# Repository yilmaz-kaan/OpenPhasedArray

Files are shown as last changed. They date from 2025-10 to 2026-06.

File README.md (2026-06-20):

# beamers
Rice University 2025-2026 ECE Senior Capstone Project Repository
Team BEAMFORM

The OpenPhasedArray is an open-source, modular 4-element transceiver phased-array
board adaptable across software-defined radio platforms and optimized for S-band
frequencies. It is ideal for hobby or research-grade beamforming experiments or sensing
and communications prototyping. It is a modular design that is easily stackable both
vertically and horizontally using the provided 3D-printable board mount. It is (optionally) interfaced with by the FT232H USB-to-serial
converter for easy, Python-based control. 

**Specification and Info**
- 2.4 – 3.7 GHz operating frequency
- Small form factor, 4.128” x 3.534”
- 21 dB peak gain per channel in TX
- 14 dB peak gain per channel in RX
- 5.625° nominal phase shifter resolution with 64 states
- 0.254 dB attenuator resolution with 128 states
- 500 ns typical TX/RX switching time
- 6V DC Power thru barrel jack-- 16V maximum
- <1mA quiescent current, 700mA maximum @ 6V input

**Repo Contents**
- Hardware
    - OpenPhasedArray schematic, design, and gerber files
    - Evaluation boards for most RF components used on the OpenPhasedArray
    - An 8-element microstrip patch antenna array that can be paired with the OpenPhasedArray
    - The original 'TXBoard' Prototype schematic, design, and gerber files
    - The secondary 'TXBoard2' Prototype schematic, design, and gerber files
    - 'STM32EVAL,' an experiment for future revisions that allow much larger scale integration
- Software
    - Control code for various versions of the board, except for Rev. 2 due to layout errors.
    - Leftover code and scripts from testing and demonstrating board performance in an Anechoic chamber

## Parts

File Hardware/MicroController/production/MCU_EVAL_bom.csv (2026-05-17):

Designator | Footprint | Quantity | Value | LCSC Part #
C1, C14, C20 | 0603 | 3 | 10uF
C15, C17, C18, C21, C25, C26, C27, C28, C30 | 0402 | 9 | 100nF
C16, C3 | 0402 | 2 | 10pF
C22, C23 | 0603 | 2 | 2u2F
C24 | 0603 | 1 | 4u7F
C29 | 0402 | 1 | 1uF
C4, C9 | 0402 | 2 | 30pF
D1 | LTST-C190KGKT | 1 | BLINK
D2 | SOD3715X145N | 1 | 1N5819HW-7-F
D3 | LTST-C190KGKT | 1 | PWRLED
J1 | HRO_TYPE-C-31-M-12 | 1 | TYPE-C-31-M-12
J2 | SHDRRA3W50P0X200_1X3_800X775X530P | 1 | OUT
J3 | PinHeader_1x12_P2.54mm_Vertical | 1 | Conn_01x12
J4 | PinHeader_1x04_P2.54mm_Vertical | 1 | Conn_01x04
J5 | PinHeader_1x08_P2.54mm_Vertical | 1 | Conn_01x08
J6 | SHDRRA3W50P0X200_1X3_800X775X530P | 1 | IN
J7 | PinHeader_1x09_P2.54mm_Vertical | 1 | Conn_01x09
R1, R4, R6, R7 | 0402 | 4 | 10k
R2, R5 | 0402 | 2 | 5k1
SW1, SW2 | SW_PTS810_SJM_250_SMTR_LFS | 2 | PTS810_SJM_250_SMTR_LFS
U1 | SOT-23-6 | 1 | USBLC6-2SC6
U2 | LD1117 | 1 | LD1117S33TR
U3 | 8SOICN_MXL | 1 | SP3485CN-L
U4 | STM32H573RIT6 | 1 | STM32H573RIT6
XTAL1 | SC32S-7PF20PPM | 1 | SC32S-7PF20PPM
Y1 | ECS-80-18-23B-JTN-TR | 1 | ECS-80-18-23B-JTN-TR

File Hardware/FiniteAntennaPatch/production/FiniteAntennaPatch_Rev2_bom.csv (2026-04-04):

Designator | Footprint | Quantity | Value | LCSC Part #
J11, J12, J21, J22, J31, J32, J41, J42 | LINX_CONSMA001-SMD-G-T | 8 | CONSMA001-SMD-G-T

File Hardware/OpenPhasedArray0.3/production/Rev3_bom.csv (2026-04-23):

Designator | Footprint | Quantity | Value | LCSC Part #
AT0, AT1, AT2, AT3 | QFN50P300X300X90-17N | 4 | RFSA3713TR7
C1, C10, C101, C13, C14, C2, C20, C4, C61, C62, C68, C94, C95 | 0402 | 13 | 0.1uF
C100, C103, C106, C107, C108, C12, C17, C18, C19, C22, C25, C26, C27, C38, C39, C40, C65, C66, C67, C7, C70, C73, C74, C75, C8, C9, C98, C99 | 0402 | 28 | 1.3 pF
C102, C11, C115, C120, C15, C16, C21, C3, C35, C5, C6, C63, C64, C69, C83, C96, C97 | 0402 | 17 | 100pF
C104, C23, C36, C71 | 0402 | 4 | 470p
C105, C24, C37, C72 | 0402 | 4 | 1uF
C109, C110, C126, C127, C129, C130, C141, C149, C28, C29, C56, C57, C76, C77, C89, C90 | 0402 | 16 | 22 pF
C111, C132, C30, C41, C50, C60, C78, C93 | 0402 | 8 | 18 pF
C112, C113, C116, C125, C31, C55, C79, C88 | 0402 | 8 | 18pF
C114, C121, C51, C84 | 0402 | 4 | 10uF
C117, C119, C128, C133, C134, C32, C34, C42, C44, C48, C58, C80, C82, C91 | 0402 | 14 | 1 uF
C118, C122, C123, C124, C131, C33, C43, C45, C46, C47, C49, C52, C53, C54, C59, C81, C85, C86, C87, C92 | 0402 | 20 | 100 pF
C135, C137, C140, C142 | 0805 | 4 | 10 uF
C136 | 0603 | 1 | 2.2 uF
C138 | 0603 | 1 | 1 uF
C139 | 0805 | 1 | 47 uF
C143, C144, C145 | 0603 | 3 | 1uF
CPL0, CPL1, CPL2, CPL3 | BDCA11040 | 4 | BDCA1-10-40+
CPL_PORT0, CPL_PORT1, CPL_PORT2, CPL_PORT3 | SMA_Amphenol_901-144_Vertical | 4 | Conn_Coaxial
DEVICE_ID1 | 0805 | 1 | LED
IC1, IC2, IC3 | QFN51P300X300X99-13N | 3 | GP2Y1+
J0, J1, J2, J3, RF_IN1 | LINX_CONSMA022-G | 5 | CONSMA022-G
J10, J11, J4, J5, J6, J7, J8, J9 | MM80302610RJ3 | 8 | MM8030-2610RJ3
J18 | PinHeader_1x08_P2.54mm_Vertical | 1 | Conn_01x08
J19 | 694106301002_1 | 1 | 694106301002
JP1 | PinHeader_1x11_P2.54mm_Vertical | 1 | FT232H_header_bottom
JP2 | PinHeader_1x11_P2.54mm_Vertical | 1 | FT232H_header_top
L1, L10, L12, L13, L14, L15, L17, L18, L2, L20, L21, L22, L23, L24, L25, L27, L28, L3, L30, L31, L32, L34, L35, L36, L38, L39, L4, L5, L6, L7, L8, L9 | 0201 | 32 | L_Ferrite
L11, L19, L29, L40 | 0603 | 4 | 12 nH
L16, L26, L33, L37 | 0603 | 4 | 12nH
LDO_1V8 | SOT95P280X100-5N | 1 | ADPL40502AUJZ-1.8-R7
LDO_NEG5 | QFN65P400X400X80-17N-D | 1 | ADP5600ACPZ-R7
LDO_POS5 | QFN65P500X500X100-21N-D | 1 | TPS7A4701RGWT
LNA0, LNA1, LNA2, LNA3 | QFN51P300X300X89-13N | 4 | PMA3-63GLN+
PA0, PA1, PA2, PA3 | QPA9122TR7 | 4 | QPA9122TR7
PS0, PS1, PS2, PS3 | QFN50P400X400X100-25N-D | 4 | MAPS-010164-TR0500
R1, R2 | 0402 | 2 | 1M
R10, R11, R3, R5, R6, R7, R8, R9 | 0402 | 8 | 0
R12, R13, R14, R15, R16, R17, R18, R19, R20, R21, R22, R23, R24, R27, R28, R30, R31, R33, R34, R35, R36, R37, R4, R40, R41, R42, R43, R44, R45, R46, R47, R50 | 0402 | 32 | 50
R25, R29, R38, R48 | 0402 | 4 | 8.2
R26, R32, R39, R49 | 0402 | 4 | 51
R51, R52, R53, R54, R55, R56, R57, R58 | 0402 | 8 | 20k
R59 | 0402 | 1 | 10k
R60 | 0402 | 1 | 100
SW00, SW01, SW10, SW11, SW20, SW21, SW30, SW31 | QFN50P300X300X90-17N-D | 8 | PE42423B-Z
U1 | SOIC127P780X200-16N | 1 | SN74HCT138NSR

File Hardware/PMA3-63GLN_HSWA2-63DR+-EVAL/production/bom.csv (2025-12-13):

Designator | Footprint | Quantity | Value | LCSC Part #
C1, C2 | 0603 | 2 | C
C3 | 0603 | 1 | 22 pF
C4, C5 | 0402 | 2 | 18pF
C6 | 0603 | 1 | 100pF
C7 | 1206 | 1 | 10uF
IC1 | QFN51P300X300X89-13N | 1 | PMA3-63GLN+
IC2 | QFN50P300X300X90-17N-D | 1 | PE42423B-Z
J1, J2, J3, J4, J5, J6, J7 | SMA_Samtec_SMA-J-P-H-ST-EM1_EdgeMount | 7 | Conn_Coaxial
J10, J8 | PinHeader_1x04_P2.54mm_Vertical | 2 | Conn_01x04_Pin
L1 | 0603 | 1 | 12nH

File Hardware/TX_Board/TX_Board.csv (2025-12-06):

Id | Designator | Footprint | Quantity | Designation | Supplier and ref
1 | IC11,IC9,IC13,IC7 | QFN50P400X400X100-25N-D | 4 | MAPS-010164-TR0500
2 | C25,C27,C73,C64,C71,C87,C63,C95,C18,C19,C45,C88,C17,C26,C40,C48,C96,C42,C72,C94,C49,C50,C68,C86,C65,C91,C22,C41 | C_0603_1608Metric | 28 | 1.3 pF
3 | C67,C15,C16,C38,C62,C61,C44,C39,C5,C21,C85,C84,C90 | C_0603_1608Metric | 13 | 100pF
4 | C28,C35,C51,C58,C81,C97,C104,C74 | C_0402_1005Metric | 8 | 18 pF
5 | R37,R25,R61,R49 | R_0603_1608Metric | 4 | 8.2
6 | C31,C98,C112,C75,C80,C77,C100,C32,C54,C29,C101,C52,C78,C110,C34,C108,C57,C103,C106,C55 | C_0603_1608Metric | 20 | 100 pF
7 | C107,C30,C111,C79,C109,C105,C53,C102,C76,C56,C99,C33 | C_0603_1608Metric | 12 | 1 uF
8 | L11,L19,L5,L20,L28,L26,L8,L12,L17,L6,L15,L14,L25,L18,L7,L10,L9,L16,L27,L13 | L_0402_1005Metric | 20 | L_Ferrite
9 | R14,R12 | R_0603_1608Metric | 2 | 453k
10 | J13,J12,J22,J10,J19,J23,J11,J14,J16,J20,J9,J17 | MM80302610RJ3 | 12 | MM8030-2610RJ3
11 | J21,J18,J15,J6 | SMA_Amphenol_901-144_Vertical | 4 | Conn_Coaxial
12 | R68,R67,R66,R69 | R_0402_1005Metric | 4 | 50
13 | C36,C4,C20,C60,C13,C82,C37,C43,C83,C89,C59,C14,C66 | C_0603_1608Metric | 13 | 0.1uF
14 | C7,C93,C70,C47,C2,C24 | C_0603_1608Metric | 6 | 1uF
15 | R44,R57,R46,R58,R35,R34,R19,R59,R23,R33,R30,R54,R43,R56,R60,R48,R42,R31,R55,R18,R20,R24,R32,R45,R22,R21,R36,R47 | R_0603_1608Metric | 28 | 50
16 | R40,R9,R6,R11,R8,R3,R52,R26,R50,R10,R62,R28,R64,R5,R38,R7 | R_0603_1608Metric | 16 | 0
17 | R17,R16,R13,R15 | R_0603_1608Metric | 4 | 49.9k
18 | J4,J3,J2,J5 | PinHeader_1x01_P2.54mm_Vertical | 4 | Conn_01x01_Pin
19 | C92,C46,C23,C69 | C_0603_1608Metric | 4 | 470p
20 | J26,J24,J27,J1,J28 | SMA_Samtec_SMA-J-P-H-ST-EM1_EdgeMount | 5 | Conn_Coaxial
21 | IC4 | SON50P300X400X80-15N-D | 1 | LT3041ADE#PBF
22 | HY4,HY2,HY3,HY1 | BDCA11040 | 4 | BDCA1-10-40+
23 | L23,L24,L21,L22 | L_0402_1005Metric | 4 | L_Ferrite
24 | IC8,IC12,IC10,IC14 | QPA9122TR7 | 4 | QPA9122TR7
25 | R27,R51,R39,R63 | R_0603_1608Metric | 4 | 51
26 | L2,L4,L3,L1 | L_0603_1608Metric | 4 | 12 nH
27 | IC3,IC2,IC1 | QFN51P300X300X89-13N | 3 | GP2Y1+
28 | C3,C6,C8,C10,C1,C9 | C_1206_3216Metric | 6 | 10uF
29 | R2,R1 | R_0603_1608Metric | 2 | 1M
30 | AT3,AT2,AT4,AT1 | QFN50P300X300X90-17N | 4 | RFSA3713TR7
31 | L31,L32,L30,L29 | L_0201_0603Metric | 4 | L_Ferrite
32 | C12,C11 | C_1206_3216Metric | 2 | 4.7uF
33 | IC5 | SON50P300X400X80-15N-D | 1 | LT3099ADE#PBF
34 | J25 | PinHeader_2x14_P2.54mm_Horizontal | 1 | Conn_02x14_Odd_Even
35 | J7 | PinSocket_1x03_P2.54mm_Vertical | 1 | Conn_01x03_Socket
36 | U1 | NS16 | 1 | SN74HCT138NSR
37 | R4 | R_0603_1608Metric | 1 | 200k
38 | J8 | PinHeader_2x08_P2.54mm_Horizontal | 1 | Conn_02x08_Odd_Even
39 | IC6 | SOT95P280X100-5N | 1 | ADPL40502AUJZ-1.5-R7

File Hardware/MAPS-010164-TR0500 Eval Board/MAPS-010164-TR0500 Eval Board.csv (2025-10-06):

Id | Designator | Footprint | Quantity | Designation | Supplier and ref
1 | J2,J6,J1,J7 | SMA_Amphenol_132289_EdgeMount | 4 | Conn_Coaxial
2 | J5 | PinHeader_2x04_P1.00mm_Vertical | 1 | Conn_02x04_Top_Bottom
3 | R4,R3,R1,R2 | C_0402_1005Metric | 4 | 10
4 | C2,C1,C8 | C_0402_1005Metric | 3 | 0.1uF
5 | J8,J4,J3 | PinHeader_2x02_P1.00mm_Vertical | 3 | Conn_02x02_Top_Bottom
6 | C5,C7,C10,C6 | C_0402_1005Metric | 4 | 300 pF
7 | C3,C9,C4 | C_0402_1005Metric | 3 | 100p
8 | IC1 | QFN50P400X400X100-25N-D | 1 | MAPS-010164-TR0500

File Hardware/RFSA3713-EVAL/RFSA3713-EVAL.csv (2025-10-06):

Id | Designator | Footprint | Quantity | Designation | Supplier and ref
1 | R3,R2,R1 | R_0402_1005Metric | 3 | 10
2 | C2 | C_0402_1005Metric | 1 | 470 pF
3 | J1,J2,J5,J4 | SMA_Amphenol_132289_EdgeMount | 4 | Conn_Coaxial
4 | C3,C4,C5 | C_0402_1005Metric | 3 | 300pF
5 | SW1,SW3,SW2 | SW_SPDT_CK_JS102011SAQN | 3 | SW_SPDT
6 | AT1 | QFN50P300X300X90-17N | 1 | RFSA3713TR7
7 | J6 | PinHeader_2x05_P1.00mm_Vertical | 1 | Conn_02x05_Odd_Even
8 | C1 | C_0402_1005Metric | 1 | 1uF

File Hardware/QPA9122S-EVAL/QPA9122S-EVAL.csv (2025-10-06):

Id | Designator | Footprint | Quantity | Designation | Supplier and ref
1 | C14,C12 | C_0402_1005Metric | 2 | 1 uF
2 | C13,C22,C17,C11 | C_0402_1005Metric | 4 | 100 pF
3 | J4,J3,J5 | PinHeader_1x02_P1.00mm_Vertical | 3 | Conn_01x02_Pin
4 | R9 | R_0402_1005Metric | 1 | 8.2
5 | J2,J7,J1,J6 | SMA_Amphenol_132289_EdgeMount | 4 | Conn_Coaxial
6 | L10 | L_0402_1005Metric | 1 | 12 nH
7 | C9,C10 | C_0402_1005Metric | 2 | 18 pF
8 | R4 | R_0402_1005Metric | 1 | 51
9 | R1,R2,R6 | R_0402_1005Metric | 3 | 0
10 | IC1 | QPA9122TR7 | 1 | QPA9122TR7

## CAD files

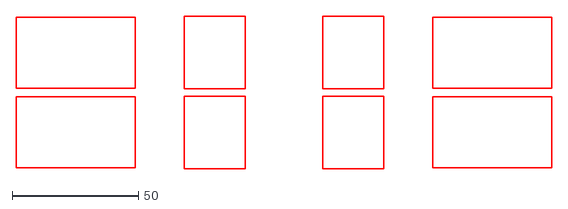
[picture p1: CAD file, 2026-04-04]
Hardware/FiniteAntennaPatch/FCu.dxf
211.8 x 60.2

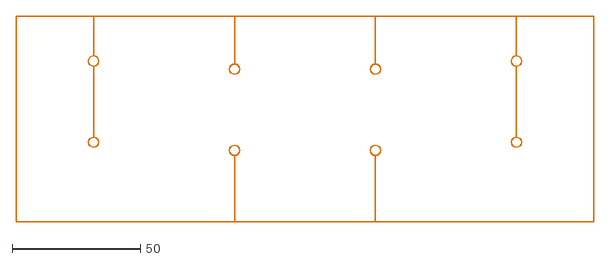
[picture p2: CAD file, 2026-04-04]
Hardware/FiniteAntennaPatch/BCu.dxf
225.0 x 80.0

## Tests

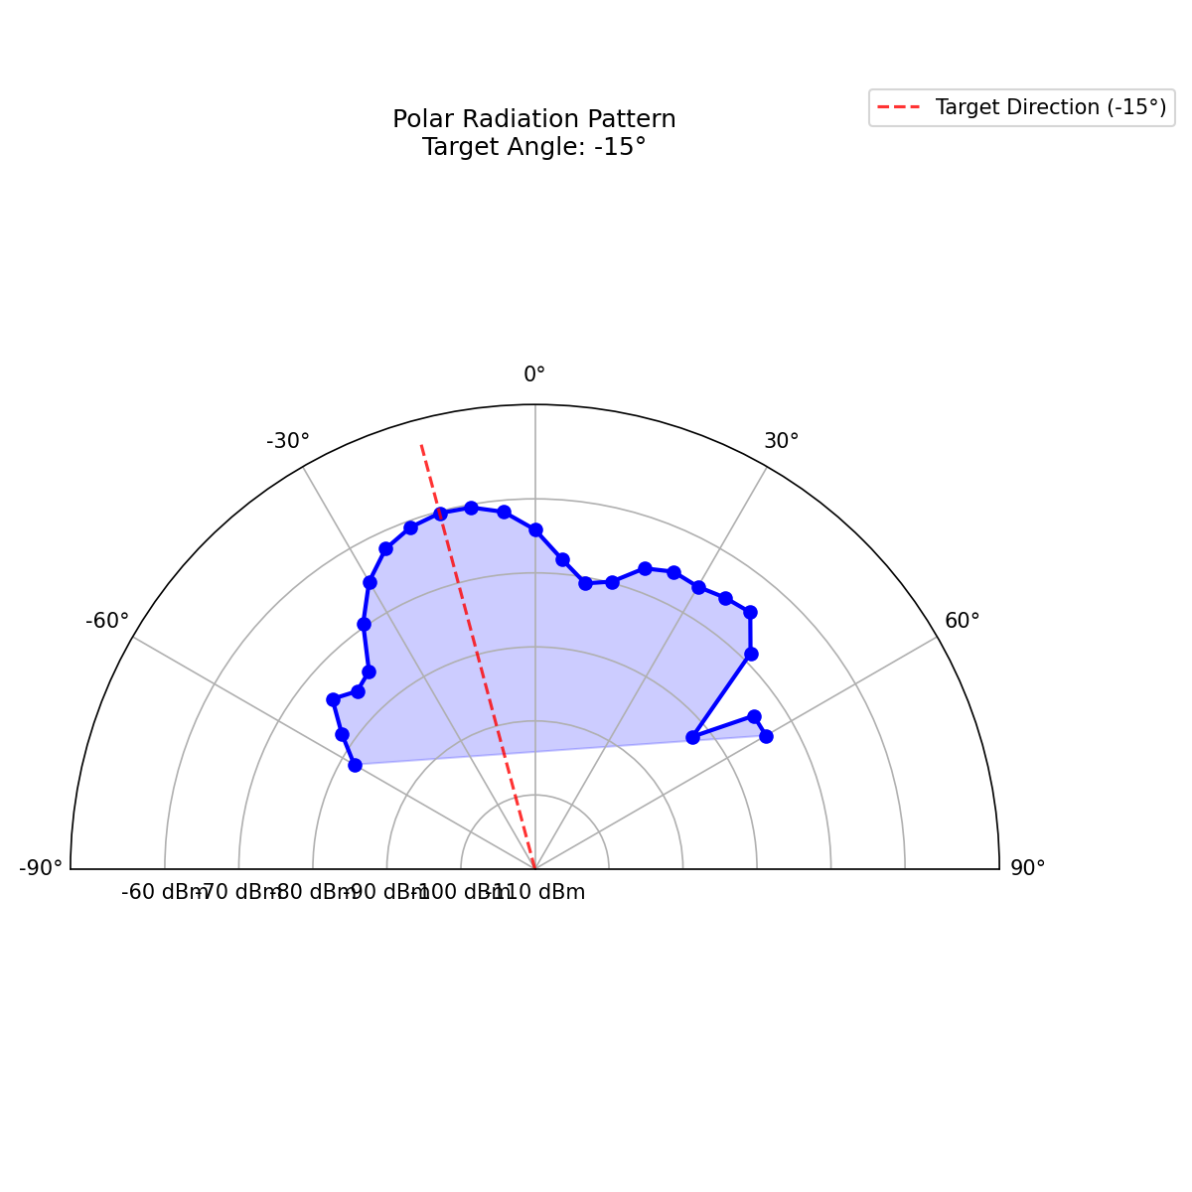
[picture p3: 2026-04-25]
Software/ChamberTesting/extracted_patterns_polar/polar_steer_-15deg.png

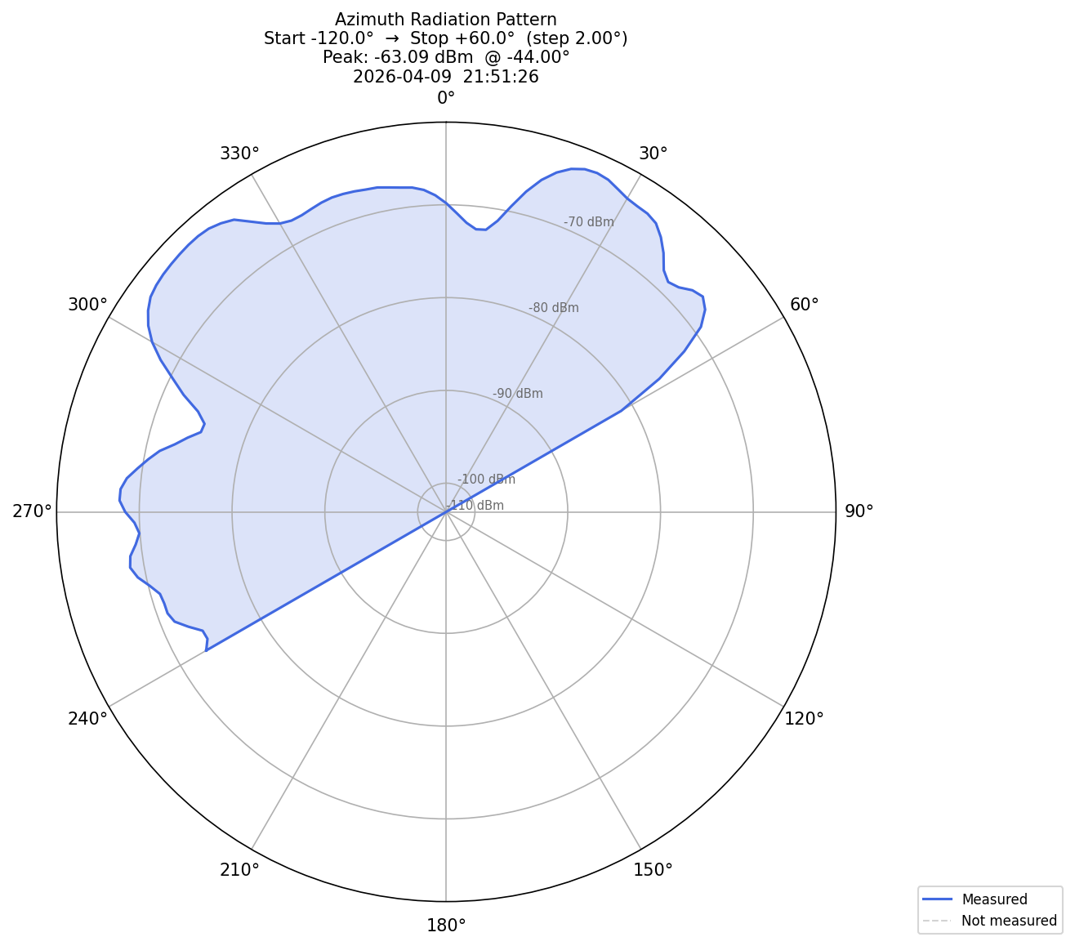
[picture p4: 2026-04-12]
Software/ChamberTesting/pattern_measurements/pattern_table+30.png

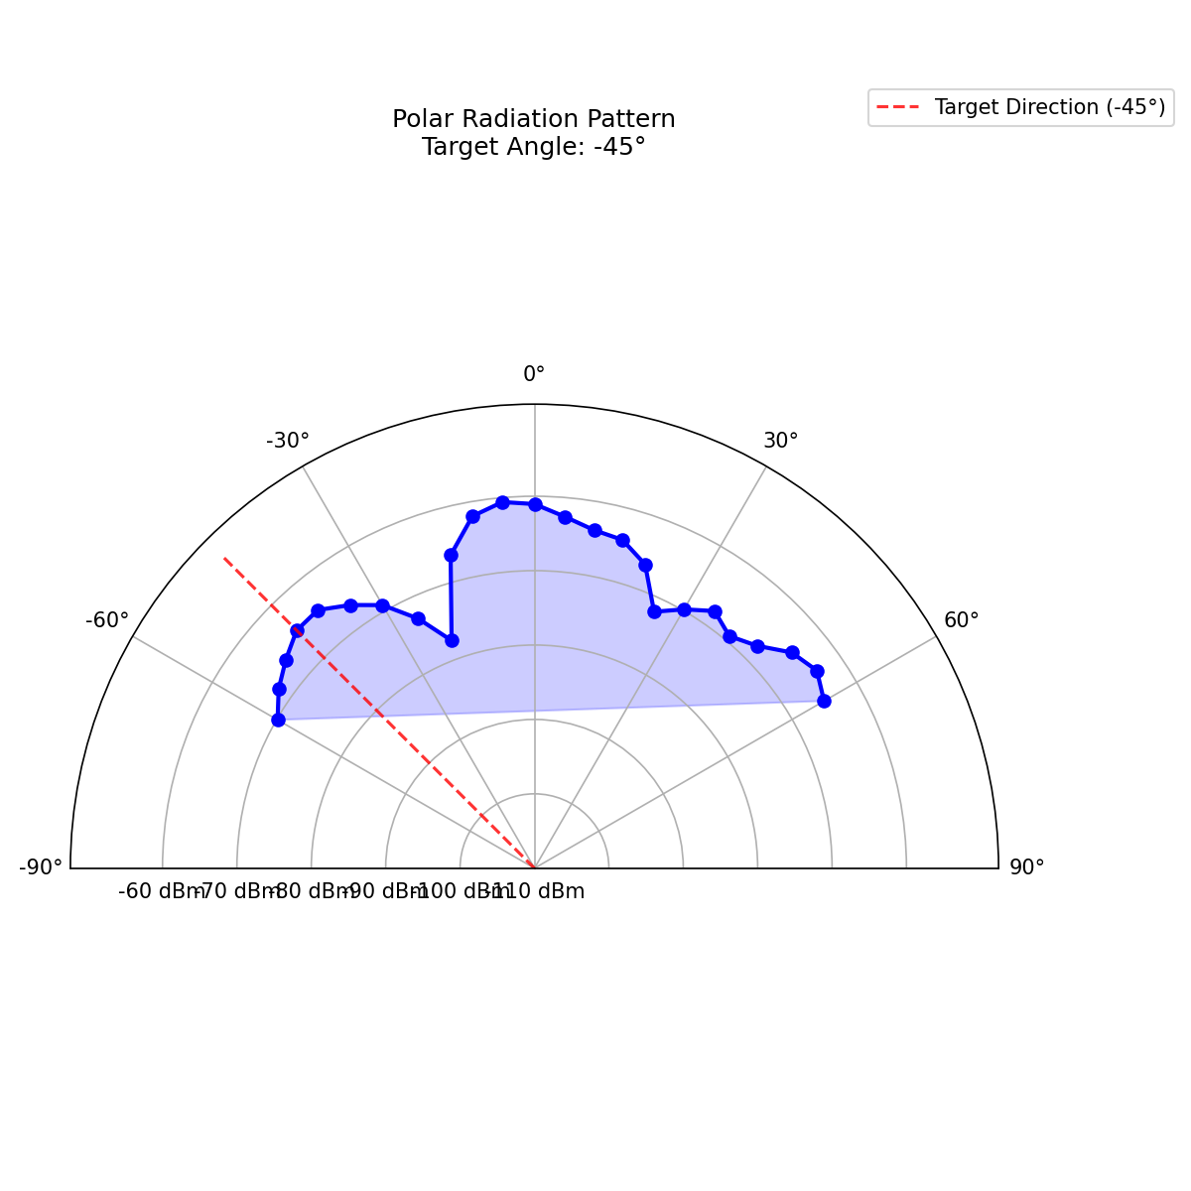
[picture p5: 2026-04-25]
Software/ChamberTesting/extracted_patterns_polar/polar_steer_-45deg.png

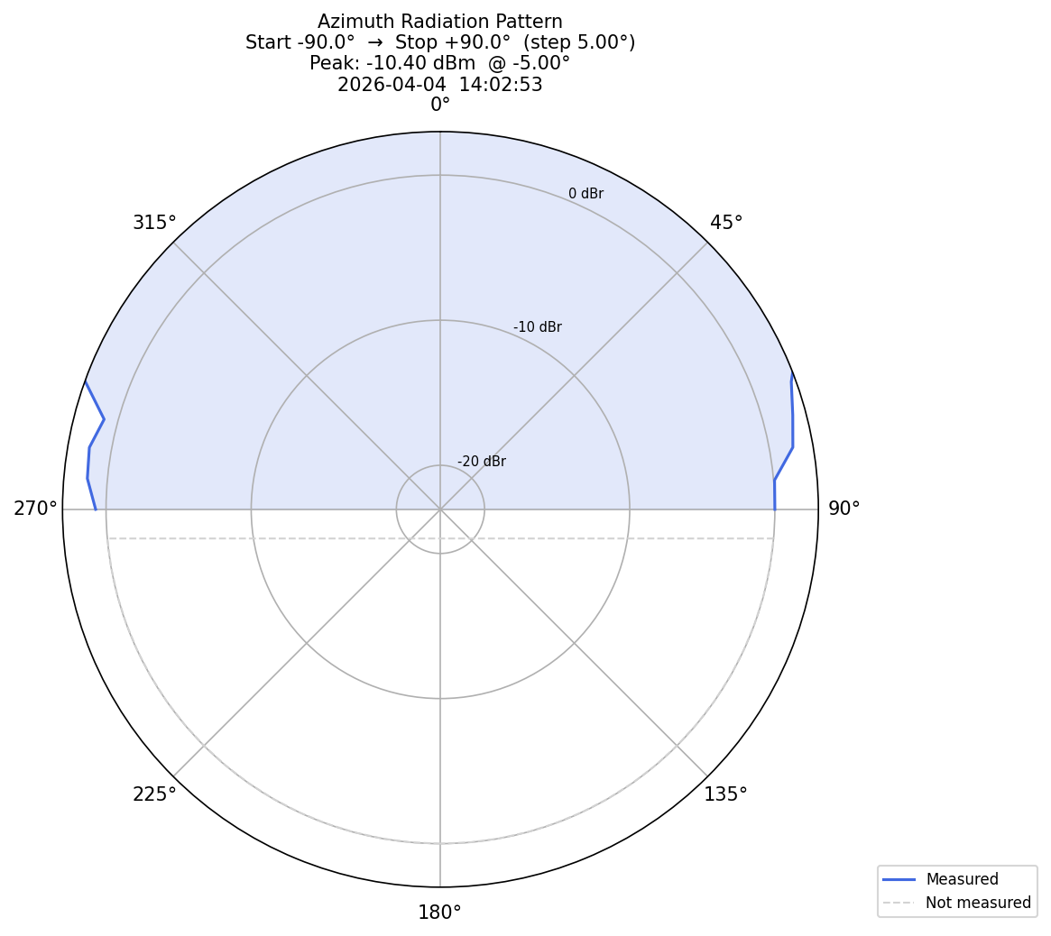
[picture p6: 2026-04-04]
Software/ChamberTesting/pattern_measurements/pattern_20260404_140219.png

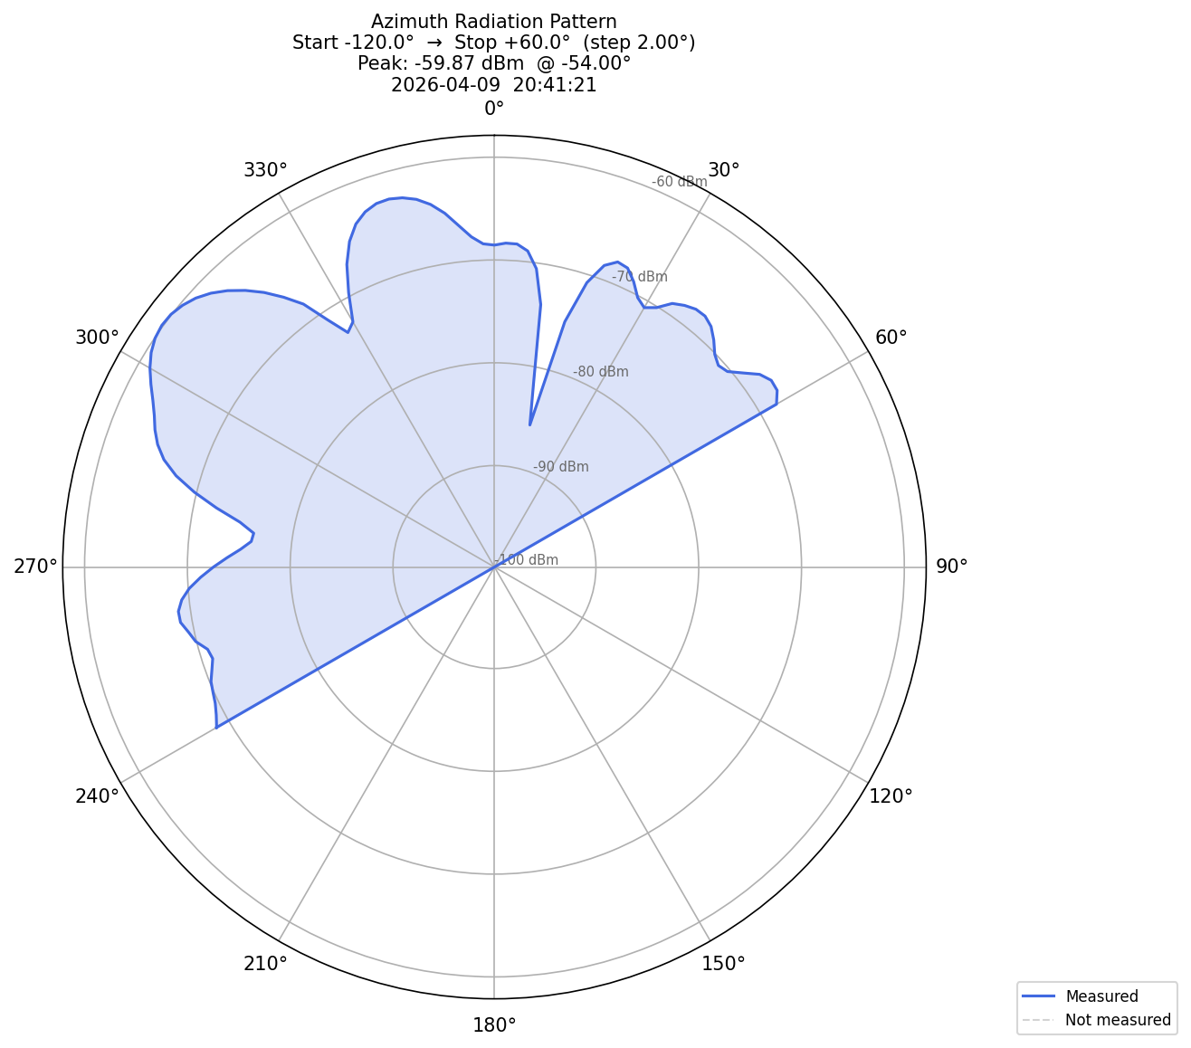
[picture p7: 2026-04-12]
Software/ChamberTesting/pattern_measurements/pattern_table-60.png

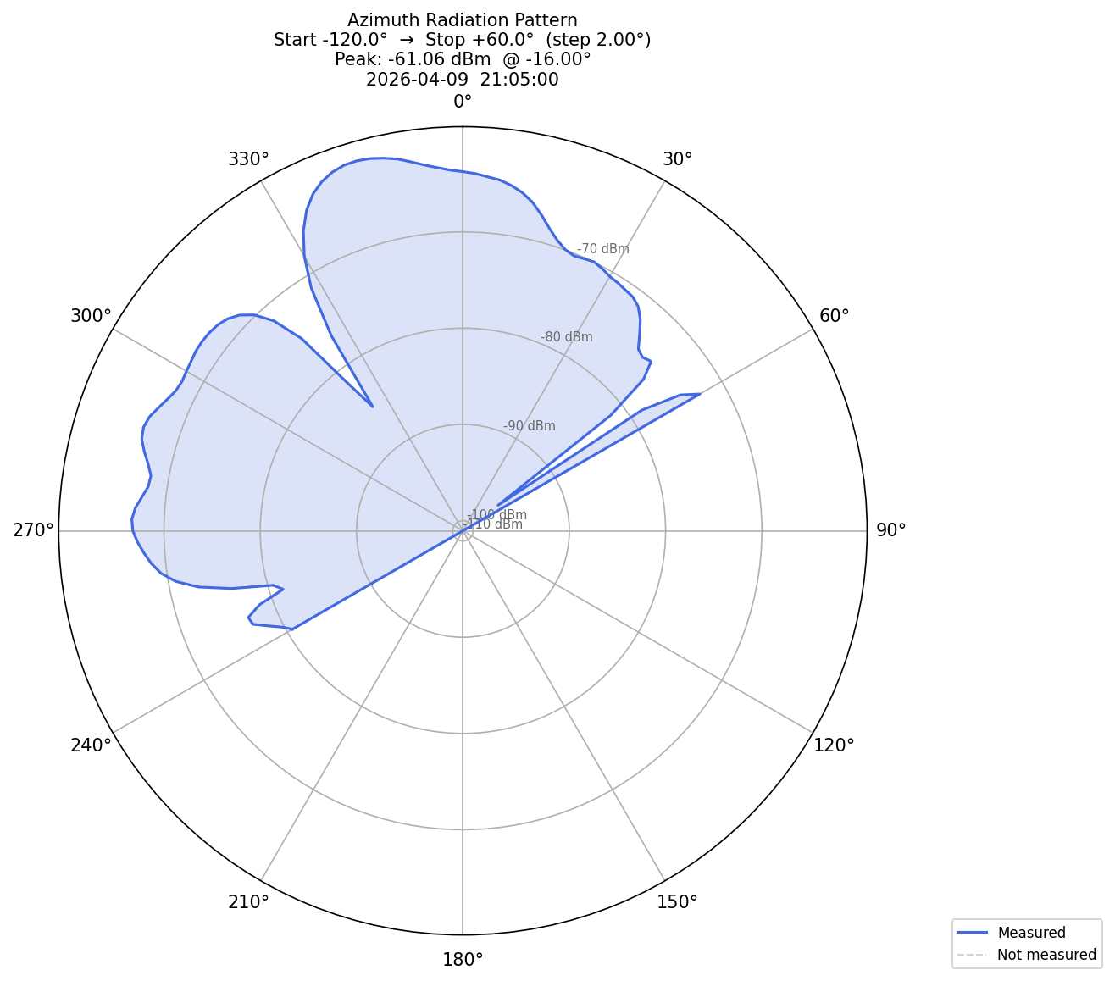
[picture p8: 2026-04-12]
Software/ChamberTesting/pattern_measurements/pattern_table-90.png

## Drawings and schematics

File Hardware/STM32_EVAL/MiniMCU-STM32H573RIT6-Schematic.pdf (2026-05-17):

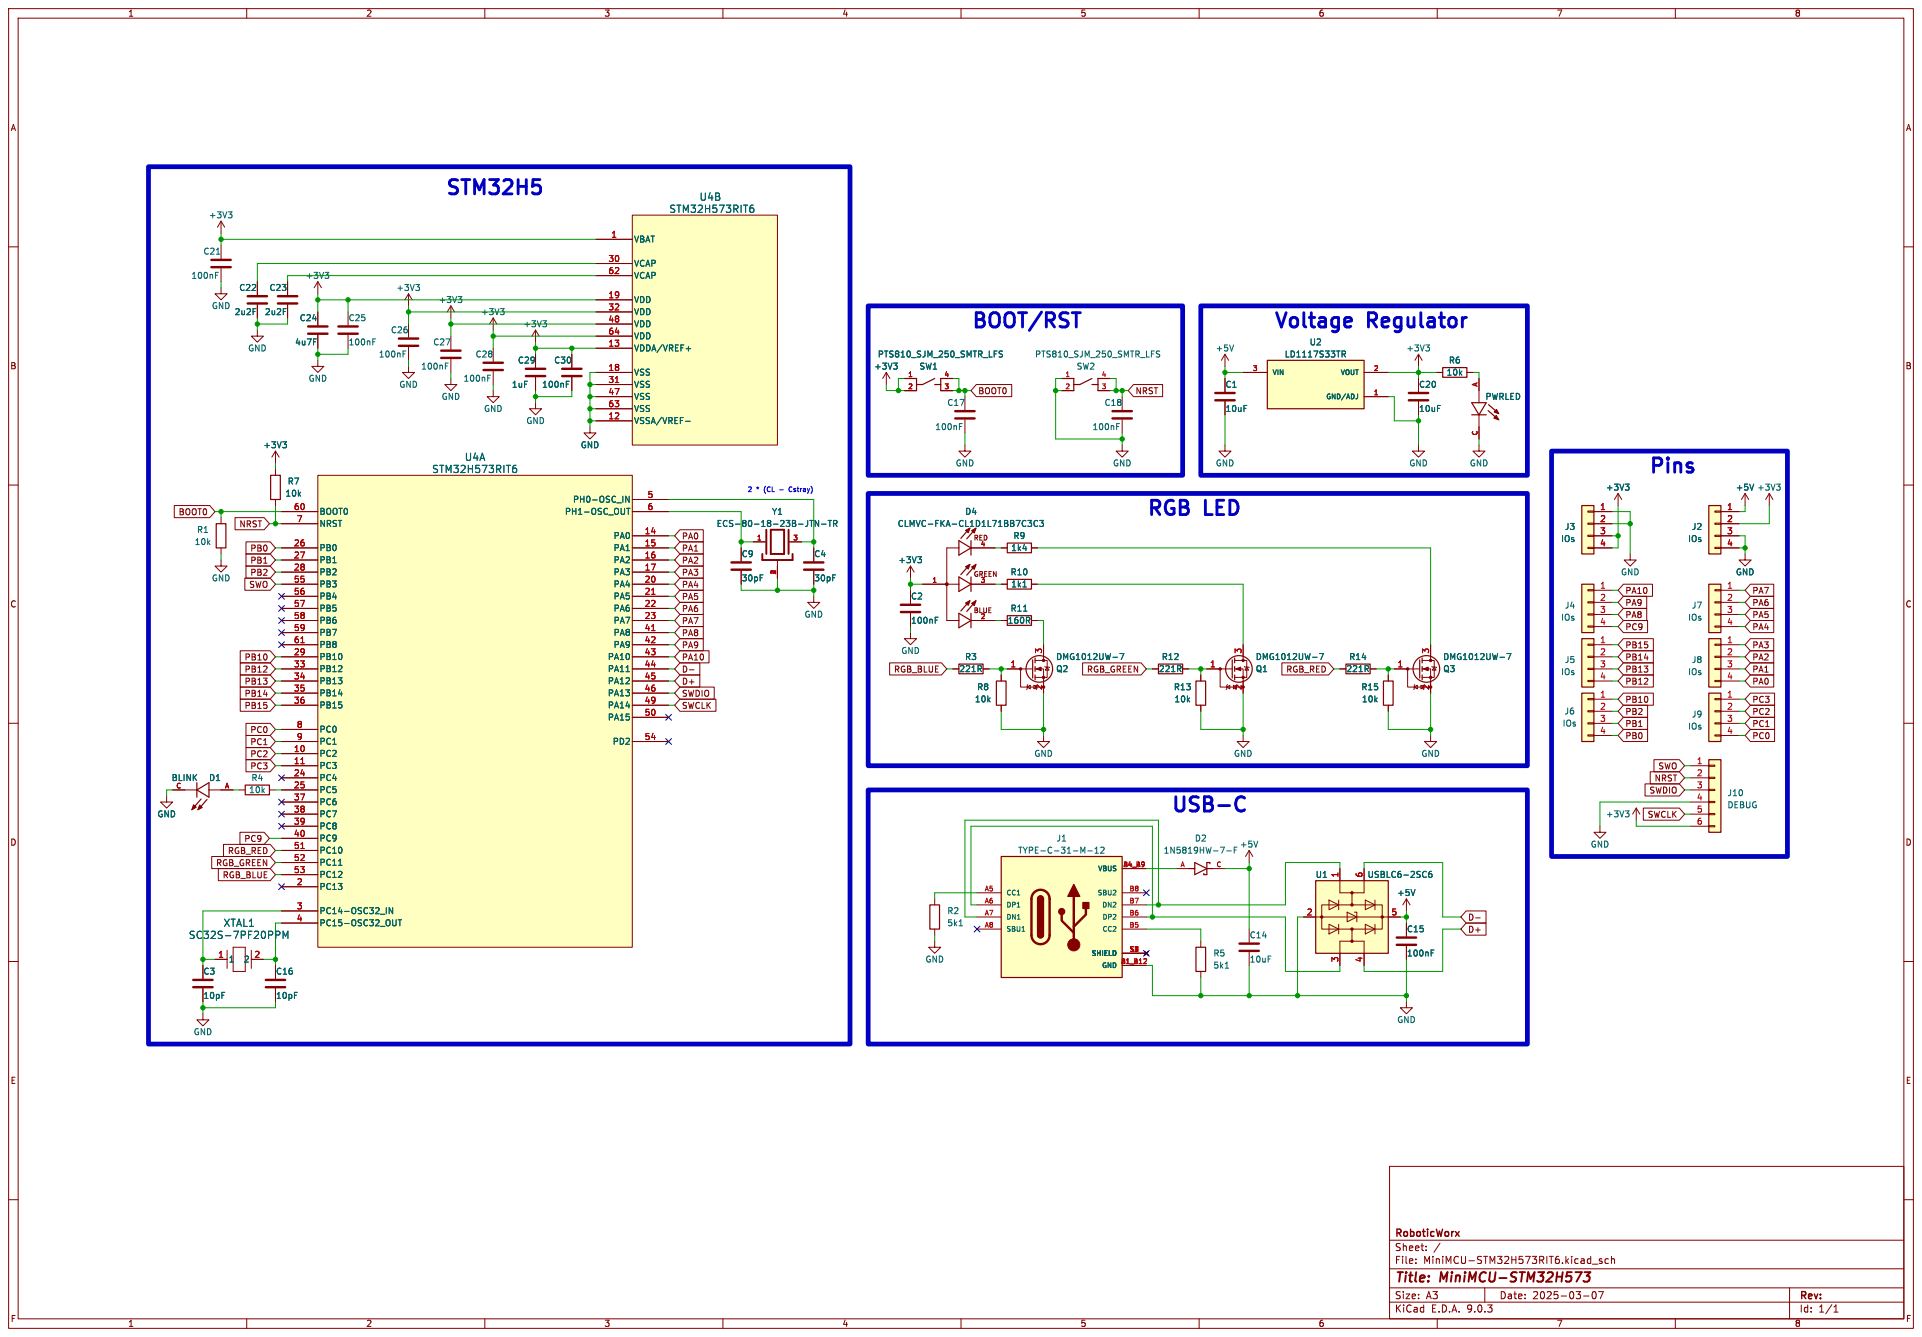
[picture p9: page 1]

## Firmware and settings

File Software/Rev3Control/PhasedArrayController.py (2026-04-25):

import os

os.environ['BLINKA_FT232H'] = '1'

import time
import board
import digitalio
import busio



# --- Pin Configuration (C bank = JP1, D bank = JP2) ---
PIN_A   = board.C0  # GPIOA   – Demux address bit A (LSB)
PIN_B   = board.C1  # GPIOB   – Demux address bit B
PIN_C   = board.C2  # GPIOC   – Demux address bit C (MSB)
PIN_TR  = board.C3  # TR_CTRL – TX (HIGH) / RX (LOW)
PIN_VEN = board.C4  # V_EN    – Enable +/- rail LDOs
PIN_VPF = board.C5  # VPD_EN  – Enable forward power amplifiers
PIN_DID = board.C6  # DEV_ID  – Identification LED
PIN_G1  = board.C7  # GPIO-G1 – Demux enable

# SPI Pins (D bank = JP2)
PIN_CLK  = board.SCK   # D0 – CLK
PIN_MOSI = board.MOSI  # D1 – SER_IN
PIN_MISO = board.MISO  # D2 – SER_OUT

# --- Demux lookup table (from datasheet, Section: Demultiplexer) ---
# SN74HCT138 index = A(LSB) + 2*B + 4*C(MSB)
# Channel numbers 0-3 correspond to board elements AT0-AT3 / PS0-PS3
ATTN_MUX = {0: 7, 1: 0, 2: 4, 3: 2}  # AT0→Y7, AT1→Y0, AT2→Y4, AT3→Y2
PS_MUX   = {0: 6, 1: 1, 2: 5, 3: 3}  # PS0→Y6, PS1→Y1, PS2→Y5, PS3→Y3


class SystemController:
    def __init__(self):
        # SPI bus (held low until V_EN is asserted)
        self.spi = busio.SPI(clock=PIN_CLK, MOSI=PIN_MOSI, MISO=PIN_MISO)
        
        # Per datasheet power-up sequence: assert ALL lines low before DC is connected
        self.a  = digitalio.DigitalInOut(PIN_A)
        self.b  = digitalio.DigitalInOut(PIN_B)
        self.c  = digitalio.DigitalInOut(PIN_C)
        self.g1 = digitalio.DigitalInOut(PIN_G1)

        for p in [self.a, self.b, self.c, self.g1]:
            p.direction = digitalio.Direction.OUTPUT
            p.value = False

        self.tr_ctrl = digitalio.DigitalInOut(PIN_TR)
        self.v_en    = digitalio.DigitalInOut(PIN_VEN)
        self.vpf     = digitalio.DigitalInOut(PIN_VPF)
        self.dev_id  = digitalio.DigitalInOut(PIN_DID)

        for p in [self.tr_ctrl, self.v_en, self.vpf, self.dev_id]:
            p.direction = digitalio.Direction.OUTPUT
            p.value = False


        self.dev_id.value = True
        print("Controller initialized. All lines low.")
        print("Connect DC barrel jack, then use VON to bring up IC rails.")

    # ------------------------------------------------------------------ #
    #  Power management  (follow datasheet power-up / power-down sequence)
    # ------------------------------------------------------------------ #

    def power_on(self):
        """
        Assert V_EN to enable +/- rail LDOs.
        DC barrel jack must already be connected before calling this.
        After this returns it is safe to use SPI, VPD_EN, and TR_CTRL.
        Default state after power-on is RX.
        """
        self.v_en.value = True
        print("V_EN asserted — +/- rails up. Safe to communicate with RFICs (default: RX).")

    def power_off(self):
        """
        Safe power-down per datasheet sequence:
        1. Stop SPI / pull demux to sleep
        2. Pull VPD_EN low
        3. Pull V_EN low
        """
        self._sleep_mux()
        self.vpf.value = False
        self.v_en.value = False
        print("VPD_EN then V_EN de-asserted — ICs off. Safe to disconnect DC.")

    def amps_on(self):
        """Assert VPD_EN to enable forward power amplifiers. V_EN must be on first."""
        self.vpf.value = True
        print("VPD_EN asserted — power amplifiers enabled.")

    def amps_off(self):
        """De-assert VPD_EN to disable forward power amplifiers."""
        self.vpf.value = False
        print("VPD_EN de-asserted — power amplifiers disabled.")

    # ------------------------------------------------------------------ #
    #  Demux control
    # ------------------------------------------------------------------ #

    def _select_mux(self, index: int):
        """
        Drive A/B/C address lines and assert G1 to enable one demux output (active LOW).
        The selected Y output goes LOW, which holds CS low on the target RFIC
        for the duration of the SPI transaction.
        """
        self.a.value  = bool(index & 0b001)
        self.b.value  = bool(index & 0b010)
        self.c.value  = bool(index & 0b100)
        self.g1.value = True

    def _sleep_mux(self):
        """
        De-assert G1 — all demux Y outputs return HIGH.
        The rising edge on the selected line latches data into the RFIC.
        Leave the demux in this state when idle.
        """
        self.g1.value = False

    # ------------------------------------------------------------------ #
    #  SPI helpers
    # ------------------------------------------------------------------ #

    @staticmethod
    def _reverse_bits(byte_val: int) -> int:
        """Reverse bit order for LSB-first devices (RFSA3713 attenuator)."""
        return int('{:08b}'.format(byte_val)[::-1], 2)

    def _spi_write(self, data: bytearray):
        while not self.spi.try_lock():
            pass
        try:
            self.spi.write(data)
        finally:
            self.spi.unlock()

    # ------------------------------------------------------------------ #
    #  RFIC commands
    # ------------------------------------------------------------------ #

    def send_phase(self, channel: int, val: int):
        """
        Write to phase shifter on channel 0-3.
        MAPS-010164 is MSB-first — no bit reversal needed.
        val: 0-63  (6-bit, 64 states, 5.625 deg/LSB)
        The demux CS line is held LOW during the transaction; the rising
        edge from _sleep_mux() latches the data into the device.
        """
        mux_idx = PS_MUX[channel]
        data = bytearray([val & 0x3F])
        self._select_mux(mux_idx)
        self._spi_write(data)
        self._sleep_mux()
        print(f"  Phase ch{channel} (PS{channel}, mux Y{mux_idx}): {val}  "
              f"({val * 5.625:.3f} deg)")

    def send_attn(self, channel: int, val: int):
        """
        Write to attenuator on channel 0-3.
        RFSA3713 is LSB-first — bits are reversed before sending.
        Two-byte transfer: data byte (reversed) then address byte (0x00, reversed).
        val: 0-127  (7-bit, 128 states, 0.254 dB/LSB)
        The demux CS line is held LOW during the transaction; the rising
        edge from _sleep_mux() latches the data into the device.
        """
        mux_idx = ATTN_MUX[channel]
        data = bytearray([
            self._reverse_bits(val & 0x7F),
            self._reverse_bits(0x00),
        ])
        self._select_mux(mux_idx)
        self._spi_write(data)
        self._sleep_mux()
        print(f"  Attn  ch{channel} (AT{channel}, mux Y{mux_idx}): {val}  "
              f"({val * 0.254:.3f} dB)")


# ------------------------------------------------------------------ #
#  CLI helpers
# ------------------------------------------------------------------ #

def parse_four_values(tokens):
    """Parse exactly 4 integer values from a token list, with a clear error."""
    if len(tokens) != 4:
        raise ValueError(f"Expected 4 values (one per channel), got {len(tokens)}.")
    return [int(t) for t in tokens]


# ------------------------------------------------------------------ #
#  Main
# ------------------------------------------------------------------ #

if __name__ == '__main__':
    ctrl = SystemController()

    print("\n--- Command Interface ---")
    print("  P <v0> <v1> <v2> <v3>  Set phase shifters ch0-3  (values 0-63,  5.625 deg/LSB)")
    print("  A <v0> <v1> <v2> <v3>  Set attenuators    ch0-3  (values 0-127, 0.254 dB/LSB)")
    print("  TX / RX                Switch transmit (HIGH) / receive (LOW)")
    print("  VON  / VOFF            IC rail power via V_EN    (VON after connecting DC)")
    print("  PON  / POFF            Amp power via VPD_EN")
    print("  EXIT                   Safe shutdown")
    print()
    print("  e.g.  P 0 16 32 48   → PS0=0°, PS1=90°, PS2=180°, PS3=270°")
    print("  e.g.  A 0 10 20 30   → AT0=0dB, AT1=2.54dB, AT2=5.08dB, AT3=7.62dB")

    try:
        while True:
            raw = input("\nEnter Command: ").strip()
            if not raw:
                continue
            tokens = raw.upper().split()
            base = tokens[0]

            if base == 'EXIT':
                break

            elif base == 'TX':
                ctrl.tr_ctrl.value = True
                print("Mode: TX")

            elif base == 'RX':
                ctrl.tr_ctrl.value = False
                print("Mode: RX")

            elif base == 'VON':
                ctrl.power_on()

            elif base == 'VOFF':
                ctrl.power_off()

            elif base == 'PON':
                ctrl.amps_on()

            elif base == 'POFF':
                ctrl.amps_off()

            elif base == 'P':
                try:
                    vals = parse_four_values(tokens[1:])
                    print("Setting phase shifters:")
                    for ch, v in enumerate(vals):
                        ctrl.send_phase(ch, v)
                except (ValueError, KeyError) as e:
                    print(f"  Error: {e}")
                    print("  Usage: P <v0> <v1> <v2> <v3>  (0-63 each)")

            elif base == 'A':
                try:
                    vals = parse_four_values(tokens[1:])
                    print("Setting attenuators:")
                    for ch, v in enumerate(vals):
                        ctrl.send_attn(ch, v)
                except (ValueError, KeyError) as e:
                    print(f"  Error: {e}")
                    print("  Usage: A <v0> <v1> <v2> <v3>  (0-127 each)")

            else:
                print(f"  Unknown command '{base}'. Type EXIT to quit.")

    finally:
        # Safe power-down sequence per datasheet
        ctrl._sleep_mux()
        ctrl.vpf.value = False
        ctrl.v_en.value = False
        ctrl.dev_id.value = False
        print("Hardware safely de-initialized.")

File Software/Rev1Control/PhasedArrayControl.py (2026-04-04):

# FT232H TX Board control script
# To setup, follow instructions at: https://learn.adafruit.com/circuitpython-on-any-computer-with-ft232h/setup
# format for instruction is "<Mode><Device Number> <Value>" (ex. A1 0 to set Attenuator 1 to 0)


import os

os.environ['BLINKA_FT232H'] = '1'


import time
import board
import digitalio


# --- Configuration for SN74HCT138 Connections ---
# command threshold to ensure proper timing between commands
cmd_threshold = 45e-9  # 45 nanoseconds
# Select pins (A, B, C) and G1 mapped to FT232H C-pins
# C is MSB | B is middle | A is LSB
PIN_C = board.C0 
PIN_B = board.C1
PIN_A = board.C2
PIN_G1 = board.C3 # Active-High Enable (Pins G2A/G2B are hardwired to GND)
PIN_SPI_CLK = board.SCK # D0
PIN_SPI_MOSI = board.MOSI # D1
PIN_SPI_MISO = board.MISO # D2
# Store the pin objects as a global list for easy management
decoder_pin_objects = []

def setup_decoder():
    """
    Initializes the GPIO pins as digital outputs and enables the decoder.
    Returns a list of DigitalInOut objects: [C_pin, B_pin, A_pin, G1_pin].
    """
    
    #  Create DigitalInOut objects
    pin_c = digitalio.DigitalInOut(PIN_C)
    pin_b = digitalio.DigitalInOut(PIN_B)
    pin_a = digitalio.DigitalInOut(PIN_A)
    pin_g1 = digitalio.DigitalInOut(PIN_G1)
    
    #  Set all pins to output direction
    pin_c.direction = digitalio.Direction.OUTPUT
    pin_b.direction = digitalio.Direction.OUTPUT
    pin_a.direction = digitalio.Direction.OUTPUT
    pin_g1.direction = digitalio.Direction.OUTPUT
    
    #  Enable the HCT138 by setting G1 to HIGH (True)
    pin_g1.value = True 
    
    print("Decoder setup complete.")
    print("SN74HCT138 Enabled (G1=HIGH, G2A/G2B=GND).")
    
    # Store and return the pin objects: [C, B, A, G1]
    global decoder_pin_objects
    decoder_pin_objects = [pin_c, pin_b, pin_a, pin_g1]
    return decoder_pin_objects

def select_output(pin_objects, output_index):
    """
    Sets the C, B, A select pins to choose a specific output (Y0-Y7).
    
    :param pin_objects: List of pin objects [C_pin, B_pin, A_pin, G1_pin].
    :param output_index: The desired output index (0 to 7).
    """
    if not 0 <= output_index <= 7:
        raise ValueError("Output index must be between 0 and 7.")
    
    pin_c, pin_b, pin_a, pin_g1 = pin_objects
    
    # Ensure G1 is HIGH to keep the decoder enabled
    pin_g1.value = True
    

    binary_select = format(output_index, '03b')
    

    pin_c.value = binary_select[0] == '1'
    pin_b.value = binary_select[1] == '1'
    pin_a.value = binary_select[2] == '1'
    
    print(f"Selected output Y{output_index} (CBA={binary_select}). The pin is LOW.")

def disable_decoder(pin_objects):
    """
    Disables the SN74HCT138 by setting G1 to LOW, forcing all outputs Y0-Y7 to High.
    """
    _, _, _, pin_g1 = pin_objects
    
    # Set G1 LOW (False) to disable all outputs
    pin_g1.value = False
    print("Decoder disabled (G1=LOW). All outputs are High.")

import busio

# SPI Configuration
# Initialize the SPI bus on the FT232H
spi = busio.SPI(clock=board.SCK, MOSI=board.MOSI, MISO=board.MISO)

def reverse_bits(byte_val):
    """
    Reverses the bits of an 8-bit integer.
    Required because RFSA3713 Attenuator expects LSB First, but busio.SPI sends MSB First.
    """
    byte_val = ((byte_val & 0xF0) >> 4) | ((byte_val & 0x0F) << 4)
    byte_val = ((byte_val & 0xCC) >> 2) | ((byte_val & 0x33) << 2)
    byte_val = ((byte_val & 0xAA) >> 1) | ((byte_val & 0x55) << 1)
    return byte_val

def send_spi_command(device_type, device_id, value, decoder_pins):
    """
    Handles the specific protocols for Phase Shifters and Attenuators.
    
    :param device_type: 'P' for Phase Shifter, 'A' for Attenuator
    :param device_id: Integer 1-4
    :param value: Integer value to write (0-255)
        Phase Shifter is 6 bit so only 0-63
        Attenuator is 7 bit, so only 0-127
    :param decoder_pins: The list of decoder pin objects
    """
    elapsed_time = time.monotonic()
    # --- 1. Determine Decoder Output & Protocol ---
    target_y = 0
    data_bytes = bytearray()
    print(device_type)
    if device_type == 'P':
        target_y = 8 - device_id 
        # send 1 byte, the relevant 6 bits are shifted in last.
        data_bytes.append(value)

    elif device_type == 'A': 
        target_y = 4 - device_id
        
        
        # Since hardware SPI is MSB First, reverse the bits of each byte.
        reversed_val = reverse_bits(value)
        reversed_addr = reverse_bits(0x00)
        
        data_bytes.append(reversed_val)
        data_bytes.append(reversed_addr)
    
    else:
        print("Unknown Device Type")
        return

    print(f"Communicating with {device_type}{device_id} on Mux Y{target_y}...")
    
    # Select the Device (Assert CS)
    select_output(decoder_pins, target_y)
    
    # Write Data
    while not spi.try_lock():
        pass
    try:
        spi.write(data_bytes)
    finally:
        spi.unlock()
    
    # Setting G1=Low disables the decoder, forcing all Y outputs HIGH.
    # This creates the Rising Edge required to latch data.
    disable_decoder(decoder_pins)
    print("Command Sent & Latched.\n")
    elapsed_time = time.monotonic() - elapsed_time
    if elapsed_time < cmd_threshold:
        time.sleep(cmd_threshold - elapsed_time)
    print(f"Elapsed Time: {elapsed_time:.3f} seconds")
    



# Main CLI Loop
if __name__ == '__main__':
    try:
        decoder_pins = setup_decoder()
        
        while True:
            print('-' * 40)
            print("Mode Selection:")
            mode_input = input("Enter IC command (ex. 'A2 64') or 'exit': ").upper()
            
            if mode_input == 'EXIT':
                break
            mode_sel = mode_input[0]
            if mode_sel not in ['P', 'A']:
                print("Invalid mode. Please try again.")
                continue
                
            dev_sel = mode_input[1]
            if not dev_sel.isdigit() or not (1 <= int(dev_sel) <= 4):
                print("Invalid Device Number. Must be 1-4.")
                continue
                
            val_sel = mode_input[3:]
            if not val_sel.isdigit():
                print("Invalid Value.")
                continue
                
            send_spi_command(mode_sel, int(dev_sel), int(val_sel), decoder_pins)

    except Exception as e:
        print(f"An error occurred: {e}")
    finally:
        if 'decoder_pin_objects' in globals() and decoder_pin_objects:
            disable_decoder(decoder_pin_objects)
            for pin in decoder_pin_objects:
                pin.deinit()
        if 'spi' in globals():
            spi.deinit()
        print("\nHardware de-initialized.")

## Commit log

2025-09-30 PA Eval Board
    [QPA9122S-EVAL.kicad_pcb, QPA9122S-EVAL.kicad_sch]
2025-09-30 Power distribution
    [QPA9122S-EVAL.kicad_pcb, QPA9122S-EVAL.kicad_sch]
2025-09-30 Added T-line test point and better labeling.
    [QPA9122S-EVAL.kicad_pcb]
2025-09-30 DRC fixes
    [QPA9122S-EVAL.kicad_pcb, QPA9122S-EVAL.kicad_sch]
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2025-10-01 Phase shifter eval board yay
    [MAPS-010164-TR0500 Eval Board.kicad_pcb, MAPS-010164-TR0500 Eval Board.kicad_sch]
2025-10-01 T-line tuning
    [QPA9122S-EVAL.kicad_pcb]
2025-10-01 Via stitching
    [MAPS-010164-TR0500 Eval Board.kicad_pcb]
2025-10-01 QPA via stitchinc
    [QPA9122S-EVAL.kicad_pcb]
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2025-10-02 Digital Line Filtering
    [MAPS-010164-TR0500 Eval Board.kicad_pcb, MAPS-010164-TR0500 Eval Board.kicad_sch]
2025-10-02 amplifier SMA connections improvements
    [QPA9122S-EVAL.kicad_pcb]
2025-10-03 zero-ohm resistors/ferrite
    [QPA9122S-EVAL.kicad_pcb]
2025-10-03 Attenuator board. TODO: Waveguides
    [MAPS-010164-TR0500 Eval Board.kicad_pcb, MAPS-010164-TR0500 Eval Board.kicad_sch, RFSA3713-EVAL.kicad_pcb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]
2025-10-03 Added Waveguides
    [RFSA3713-EVAL.kicad_pcb]
2025-10-06 fixed attenuator board to fit DRC
    [RFSA3713-EVAL.kicad_pcb]
2025-10-06 More BoMs
    [MAPS-010164-TR0500 Eval Board.csv, RFSA3713-EVAL.csv]
2025-10-08 DRC and header re-sizing
    [MAPS-010164-TR0500 Eval Board.kicad_pcb, MAPS-010164-TR0500 Eval Board.kicad_sch, QPA9122S-EVAL.kicad_pcb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]
2025-10-08 DRC and connector sizing
    [QPA9122S-EVAL.kicad_pcb]
2025-10-08 added the gerber for the attenuator board
    [RFSA3713-EVAL-B_Cu.gbl, RFSA3713-EVAL-B_Mask.gbs, RFSA3713-EVAL-B_Paste.gbp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]
2025-10-10 started TX board schematics
    [TX_Board.kicad_pcb, TX_Board.kicad_sch]
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2025-10-11 Fixed JLCPCB Errors
    [MAPS-010164-TR0500 Eval Board-B_Cu.gbl, MAPS-010164-TR0500 Eval Board-B_Mask.gbs, MAPS-010164-TR0500 Eval Board-B_Paste.gbp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]
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2025-10-15 updated logic breakout and added UFL
    [TX_Board.kicad_sch]
2025-10-16 Power Supply Board
    [ADP5071_Dual_Supply.kicad_pcb, ADP5071_Dual_Supply.kicad_sch]
2025-10-21 updated tx board and started layour
    [TX_Board.kicad_pcb, TX_Board.kicad_sch]
2025-10-22 added LDO
    [TX_Board.kicad_pcb, TX_Board.kicad_sch]
2025-10-24 switched out UFL to SWG
    [TX_Board.kicad_pcb, TX_Board.kicad_sch]
2025-10-24 if i fuck up go back to this version
    [TX_Board.kicad_pcb]
2025-10-24 updated schematics
    [TX_Board.kicad_pcb, TX_Board.kicad_sch]
2025-10-25 refactored pcb
    [TX_Board.kicad_pcb, TX_Board.kicad_sch, untitled.kicad_sch]
2025-10-25 rough layout using replicate plugin
    [TX_Board.kicad_pcb, TX_Board.kicad_sch]
2025-10-26 Updated Layout
    [TX_Board.kicad_pcb, untitled.kicad_sch]
2025-10-26 More Layout
    [TX_Board.kicad_pcb, untitled.kicad_sch]
2025-10-28 Shrinking layout
    [TX_Board.kicad_pcb]
2025-10-28 prelim power/logic placement
    [TX_Board.kicad_pcb]
2025-10-28 Fixed mounting asymmetry
    [ADP5071_Dual_Supply.kicad_pcb]
2025-10-28 Waveguide + ground planes and P.S. daughter board modification
    [ADP5071_Dual_Supply.kicad_pcb, TX_Board.kicad_pcb, TX_Board.kicad_sch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]
2025-10-30 Ease of construction, added new layers, prelimininary routing.
    [ADP5071_Dual_Supply.kicad_pcb, ADP5071_Dual_Supply.kicad_sch, TX_Board.kicad_pcb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]
2025-10-30 more routing
    [TX_Board.kicad_pcb]
2025-10-31 routing + odb++ export
    [TX_Board.kicad_pcb]
2025-10-31 updated DRC for OSHpark
    [TX_Board.kicad_pcb]
2025-11-03 Swapped layers
    [TX_Board.kicad_pcb]
2025-11-03 Layout Tweaks
    [TX_Board.kicad_pcb]
2025-11-04 DRC and more layout
    [TX_Board.kicad_pcb, TX_Board.kicad_sch, untitled.kicad_sch]
2025-11-21 added phase shifter/VA eval code
    [a000.csv, a008.csv, a016.csv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]
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2025-12-13 LNA + Switch Test Board
    [PMA3-63GLN_HSWA2-63DR+-EVAL.kicad_pcb, PMA3-63GLN_HSWA2-63DR+-EVAL.kicad_sch]
2025-12-13 EVAL board design files
    [PMA3-63GLN_HSWA2-63DR+-EVAL.kicad_pcb, PMA3-63GLN_HSWA2-63DR+-EVAL.kicad_sch, bom.csv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]
2025-12-18 Eval board updates + bowtie antenna test
    [BowTie3G.kicad_pcb, BowTie3G.kicad_sch, PMA3-63GLN_HSWA2-63DR+-EVAL.kicad_pcb]
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2026-01-14 Added FT232H ports and positive voltage railto schematic
    [TX_Board_Rev2.kicad_sch]
2026-01-14 adjustments to power and added VPD LDO
    [TX_Board_Rev2.kicad_sch]
2026-01-15 Rev2 layout partially complete
    [TX_Board_Rev2.kicad_pcb, TX_Board_Rev2.kicad_sch, channel0.kicad_sch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]
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2026-04-04 Organization + azimuth sweep code
    [calibration_20260403_132345.csv, calibration_20260403_133017.csv, calibration_20260403_141058.csv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]
2026-04-04 Added control code for sequences of azimuth pattern measurements.
    [pattern_20260404_163844_P0-0-0-0.csv, pattern_20260404_163945_P8-16-24-32.csv, pattern_20260404_164044_P16-32-48-0.csv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]
2026-04-05 lookup table generator script
    [pattern_20260404_163844_P0-0-0-0.csv, pattern_20260404_163945_P8-16-24-32.csv, pattern_20260404_164044_P16-32-48-0.csv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]
2026-04-06 New phase sweep and better info for environment setup
    [calibration_max_20260405_172545.csv, calibration_max_20260405_172623.csv, calibration_max_20260405_172907.csv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]
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2026-04-08 FIXED SPI BUG IN REV2 CONTROLLER
    [ic_control_rev2.py]
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2026-04-17 FT232H Layout fix
    [TX_Board_Rev2.kicad_sch]
2026-04-20 Fix rev2
    [TX_Board_Rev2.kicad_sch]
2026-04-21 Rev 3, rotated interface connectors
    [TX_Board_Rev2.kicad_sch, channel0.kicad_sch, channel1.kicad_sch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]
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2026-04-25 optimal radiation patterns + a few rev 3 fixes
    [TX_Board_Rev2.kicad_sch, channel0.kicad_sch, polar_steer_-05deg.csv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]
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2026-05-17 Microcontroller schematic + design files
    [MCU_EVAL_bom.csv, MCU_EVAL_designators.csv, MCU_EVAL_positions.csv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]
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2026-06-20 Restored broken Rev 2 for posterity and cleaned up naming
    [BOM_TX_Board_Rev2.kicad_pcb 2.xlsx, BOM_TX_Board_Rev2.kicad_pcb.xls, BOM_TX_Board_Rev2.xlsx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]
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2026-08-27 clarified schematic comments, shrunk vias in QFN pads
    [TX_Board_Rev2.kicad_sch]
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
